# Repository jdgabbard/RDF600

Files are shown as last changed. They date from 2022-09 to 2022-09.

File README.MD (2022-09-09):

# RDF-600
 RDF-600 Floppy Adapter for MSX Computers.

***Based on the TDC-600***

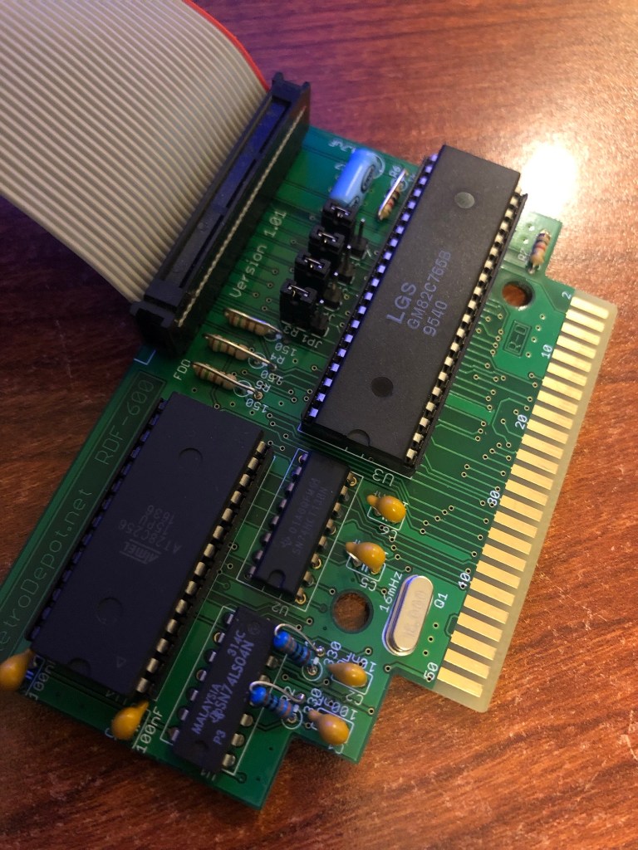
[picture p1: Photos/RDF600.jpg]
PCB


This is a clone of the TDC-600 Disk Adadpter for MSX Computers redesigned for a more compact footprint.  This should fit inside standard MSX cartridge shells that have been modified to allow for the floppy ribbon cable.

The board is compatible with the standard TDC-600 firmware.  Or, if using an imported machine in the US or UK, it can be used with the provided firmware which has been patched for the English Language.

The Original Source Code for the PCB, and a working disassembly of it, can be found here:  https://github.com/jdgabbard/TDC-600-Source-Code

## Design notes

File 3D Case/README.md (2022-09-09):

#RDF-600 Cartridge Shell

The Cartridge shell is designed to snap together.  Additionally, a small self tapping screw may be used to secure the cartridge.  Don't ask what size, I just grabbed one from my screw box that fit.

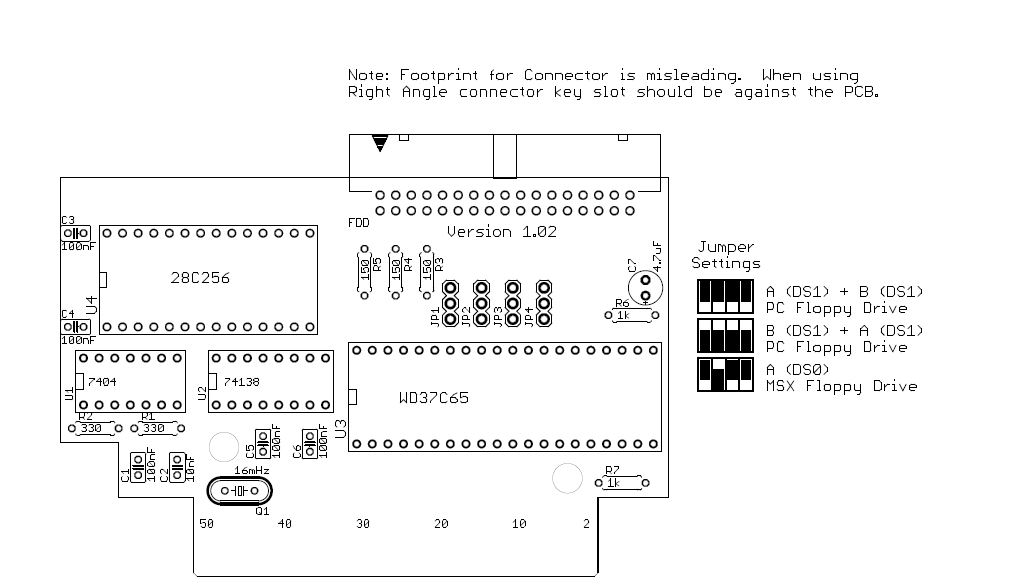
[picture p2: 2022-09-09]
Photos/Jumpers.JPG

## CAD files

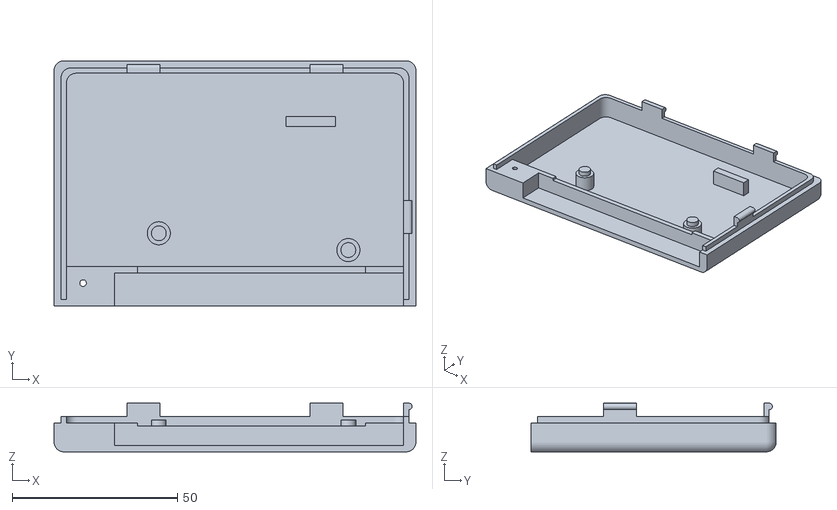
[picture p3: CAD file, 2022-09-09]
3D Case/RD_back_v2.stl
109.6 x 74.3 x 14.8

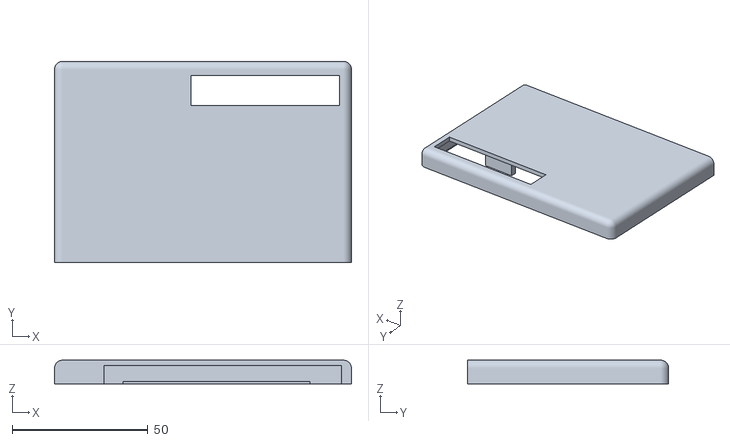
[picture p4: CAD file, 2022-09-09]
3D Case/RD_front_v2.stl
109.6 x 74.3 x 8.75

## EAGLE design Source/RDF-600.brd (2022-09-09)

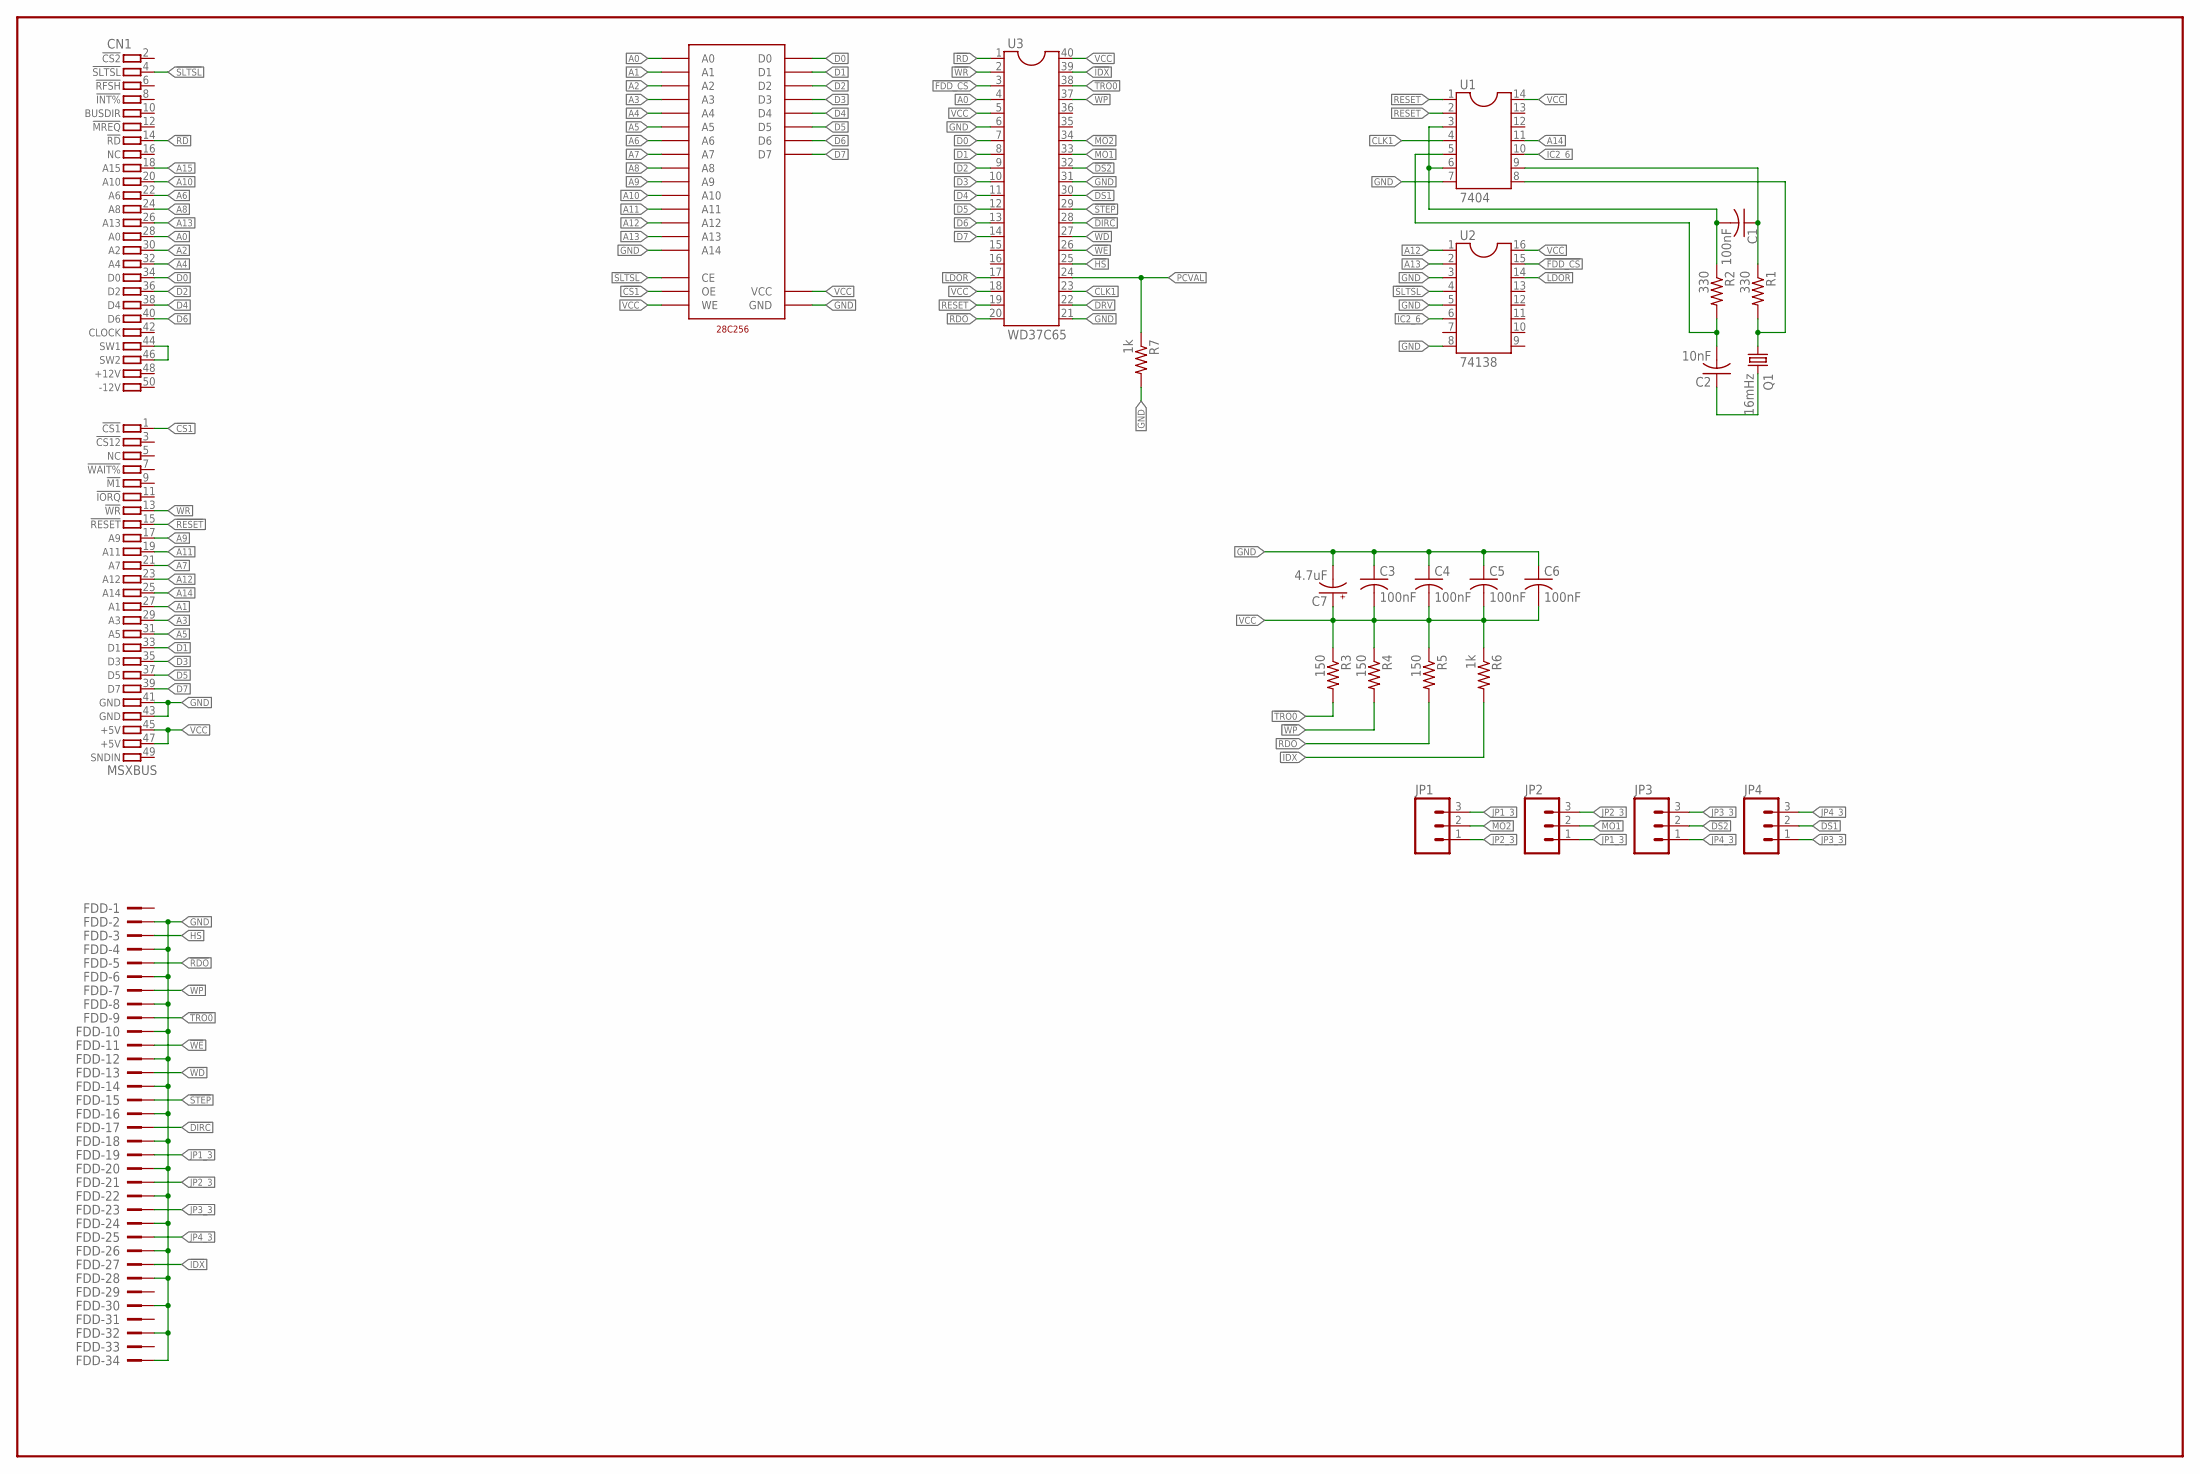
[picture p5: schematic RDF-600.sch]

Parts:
28C256: 28C256; DIP28
C1, C3, C4, C5, C6: 100nF; C025-025X050
C2: 10nF; C025-025X050
C7: 4.7uF; E2,5-6E
CN1: MSXBUS; MSXBUS_EDGECONN
FDD: 2534-5; PAK100/2500-5-34
JP1, JP2, JP3, JP4: M03PTH; 1X03
Q1: 16mHz; HC49/S
R1, R2: 330; 0207/7
R3, R4, R5: 150; 0207/7
R6, R7: 1k; 0207/7
U1: 7404; DIL14
U2: 74138; DIL16
U3: WD37C65; DIL40

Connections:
!CS1: 28C256.P$22 (OE), CN1.1 (1.!CS1)
!DIRC: FDD.17, U3.28
!DS1: JP4.2, U3.30
!DS2: JP3.2, U3.32
!FDD_CS: U2.15, U3.3
!HS: FDD.3, U3.25
!IDX: FDD.27, R6.2, U3.39
!LDOR: U2.14, U3.17
!MO1: JP2.2, U3.33
!MO2: JP1.2, U3.34
!RD: CN1.14 (14.!RD), U3.1
!RDO: FDD.5, R5.2, U3.20
!RESET: CN1.15 (15.!RESET), U1.1
!SLTSL: 28C256.P$20 (CE), CN1.4 (4.!SLTSL), U2.4
!STEP: FDD.15, U3.29
!TRO0: FDD.9, R3.2, U3.38
!WD: FDD.13, U3.27
!WE: FDD.11, U3.26
!WP: FDD.7, R4.2, U3.37
!WR: CN1.13 (13.!WR), U3.2
A0: 28C256.P$10 (A0), CN1.28 (28.A0), U3.4
A1: 28C256.P$9 (A1), CN1.27 (27.A1)
A2: 28C256.P$8 (A2), CN1.30 (30.A2)
A3: 28C256.P$7 (A3), CN1.29 (29.A3)
A4: 28C256.P$6 (A4), CN1.32 (32.A4)
A5: 28C256.P$5 (A5), CN1.31 (31.A5)
A6: 28C256.P$4 (A6), CN1.22 (22.A6)
A7: 28C256.P$3 (A7), CN1.21 (21.A7)
A8: 28C256.P$25 (A8), CN1.24 (24.A8)
A9: 28C256.P$24 (A9), CN1.17 (17.A9)
A10: 28C256.P$21 (A10), CN1.20 (20.A10)
A11: 28C256.P$23 (A11), CN1.19 (19.A11)
A12: 28C256.P$2 (A12), CN1.23 (23.A12), U2.1
A13: 28C256.P$26 (A13), CN1.26 (26.A13), U2.2
A14: CN1.25 (25.A14), U1.11
A15: CN1.18 (18.A15)
CLK1: U1.4, U3.23
D0: 28C256.P$11 (D0), CN1.34 (34.D0), U3.7
D1: 28C256.P$12 (D1), CN1.33 (33.D1), U3.8
D2: 28C256.P$13 (D2), CN1.36 (36.D2), U3.9
D3: 28C256.P$15 (D3), CN1.35 (35.D3), U3.10
D4: 28C256.P$16 (D4), CN1.38 (38.D4), U3.11
D5: 28C256.P$17 (D5), CN1.37 (37.D5), U3.12
D6: 28C256.P$18 (D6), CN1.40 (40.D6), U3.13
D7: 28C256.P$19 (D7), CN1.39 (39.D7), U3.14
DRV: U3.22
GND: 28C256.P$1 (A14), 28C256.P$14 (GND), C3.1, C4.1, C5.1, C6.1, C7.-, CN1.41 (41.GND), CN1.43 (43.GND), FDD.2, FDD.4, FDD.6, FDD.8, FDD.10, FDD.12, FDD.14, FDD.16, FDD.18, FDD.20, FDD.22, FDD.24, FDD.26, FDD.28, FDD.30, FDD.32, FDD.34, R7.2, U1.7, U2.3, U2.5, U2.8, U3.6, U3.21, U3.31
IC2_6: U1.10, U2.6
JP1_3: FDD.19, JP1.3, JP2.1
JP2_3: FDD.21, JP1.1, JP2.3
JP3_3: FDD.23, JP3.3, JP4.1
JP4_3: FDD.25, JP3.1, JP4.3
unnamed: Q1.1, R1.2, U1.8
unnamed: C2.1, Q1.2
unnamed: C2.2, R2.2, U1.5
unnamed: C1.1, R1.1, U1.9
unnamed: C1.2, R2.1, U1.3, U1.6
unnamed: CN1.44 (44.SW1), CN1.46 (46.SW2)
PCVAL: R7.1, U3.24
RESET: U1.2, U3.19
VCC: 28C256.P$27 (WE), 28C256.P$28 (VCC), C3.2, C4.2, C5.2, C6.2, C7.+, CN1.45 (45.+5V), CN1.47 (47.+5V), R3.1, R4.1, R5.1, R6.1, U1.14, U2.16, U3.5, U3.18, U3.40

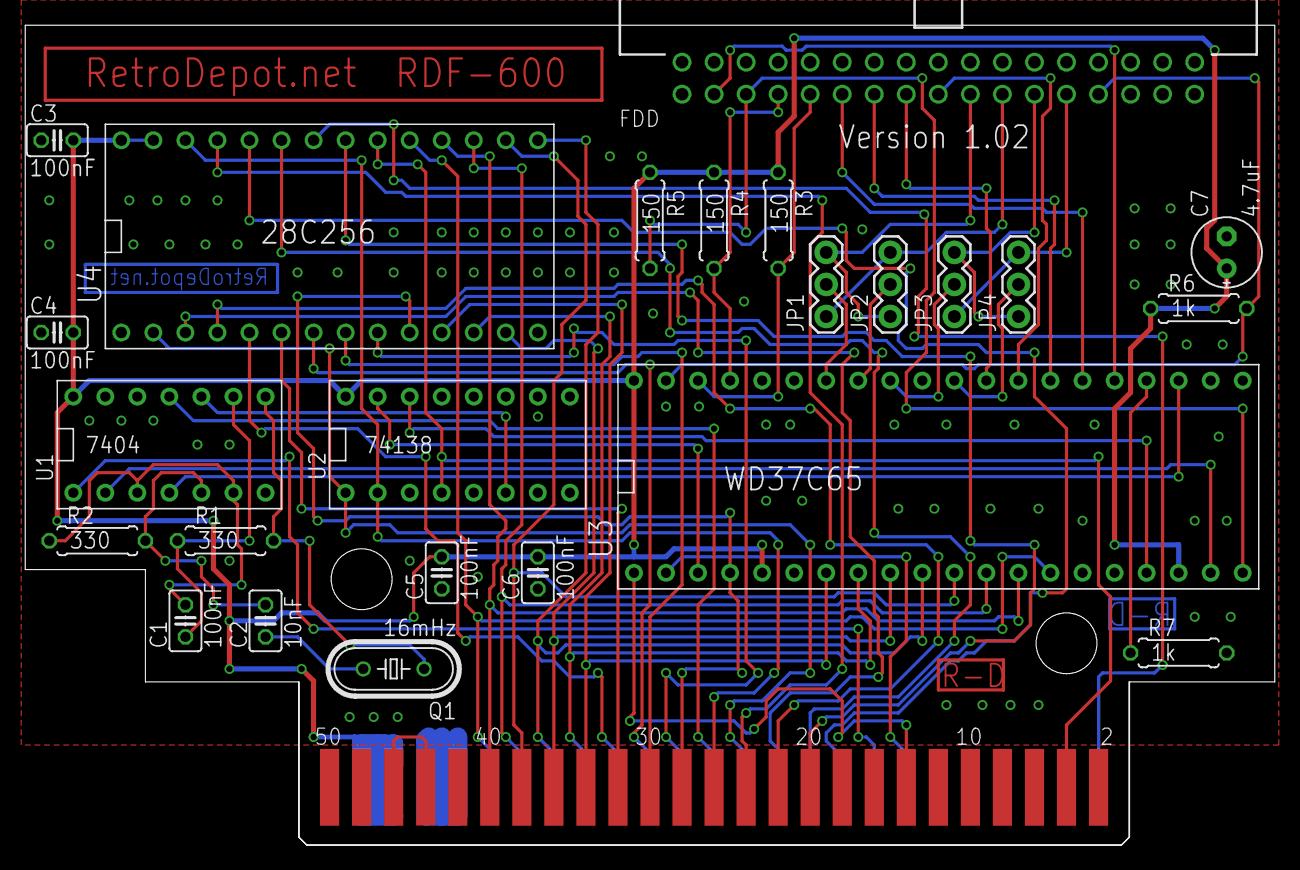
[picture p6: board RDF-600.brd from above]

Board: 2 copper layers, 99.1 x 65.0 mm, 25 parts (0 on the bottom side), 59 nets.

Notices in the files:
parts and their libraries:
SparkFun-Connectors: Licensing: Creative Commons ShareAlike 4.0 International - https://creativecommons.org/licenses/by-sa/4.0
